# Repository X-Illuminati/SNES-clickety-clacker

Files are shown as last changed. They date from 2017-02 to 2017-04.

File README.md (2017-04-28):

```
     ______     ___   ___   _______     _______   _______
    / ___. \   /  /  /  /  /  ___  \   /  ____/  /  ___  \
   / /   / /  /  /  /  /  /  /  /  /  /  /      /  /  /  /
   | \  /_/  /  /  /  /  /  /  /  /  /  /___   /  /__/  /
  _ \ \     /  /  /  /  /  /__/  /  /  ____/  /      __/
 / / \ \   /  /  /  /  /  _____,'  /  /      /  ___.  \
/ /__/ /  /  /__/  /  /  /        /  /___   /  /   /  /
\_____/   \_______/  /__/        /______/  /__/   /__/

≡≡≡≡≡≡≡≡≡≡≡≡≡≡≡≡≡≡≡≡≡≡≡≡≡≡≡≡≡≡≡≡≡≡≡≡≡≡≡≡≡≡≡≡≡≡≡≡≡≡≡≡≡≡≡≡
#    C  L  I  C  K  E  T  Y  -  C  L  A  C  K  E  R    #
≡≡≡≡≡≡≡≡≡≡≡≡≡≡≡≡≡≡≡≡≡≡≡≡≡≡≡≡≡≡≡≡≡≡≡≡≡≡≡≡≡≡≡≡≡≡≡≡≡≡≡≡≡≡≡≡
    ______    ___     ____    ____     ______    _   __
 __/ ____/___/   |___/  _/_  / __ \   / ____/   / | / /
  / / __  __/ /| |___/ /____/ / / /__/ __/__   /  |/ /
 / /_/ /   / ___ | _/ /  __/ /_/ /__/ /_______/ /|  /__
 \____/   /_/  |_|/___/   /_____/  /_____/   /_/ |_/

                            /\
  /\-----------------------/__\---------------------/\
 /--\                    CONTENTS                  /--\
/`\/`\--------------------------------------------/`\/`\
¯¯¯¯¯¯                                            ¯¯¯¯¯¯
```
- [Introduction](#introduction)
- [Thaumaturgical Design](#thaumaturgical-design)
- [Reagents](#reagents)
- [Crafting Notes](#crafting-notes)
- [Epilogue](#epilogue)

## Introduction

Hail adventurer! I see my little trinket has caught your attention.
If you're interested, I'll tell you all about it. Just pull up a stool and order
your favorite libation. I can vouch for the quality of the ale but be warned:
the bartender is an incurable gossip!

What is it, you ask? Why, it's a SNES controller. Ha! It's barely recognizable
compared to your usual, mundane variety. But, I'll get to that...

Let me tell you why it's useful -- I used to have terrible problems with the
standard SNES controller. After years of adventuring I've developed what the
seven sages call sore-thumb-itosis. Even Morgia root can't treat it once the
disease reaches it's advances stage.  
Well, this sore-thumb-itosis was preventing me from making progress in my
adventures. I couldn't even make it to base camp most of the time.  
But, fortunately, I met a fellow adventurer one evening in an inn much like this
one. He told me that he used to be a great adventurer (until he took an arrow to
the knee), and told me of others he'd met who had a similar problem.
It turns out the issue is fundamental to the design of the stock controller --
the rubber membranes make only intermittent contact and lack any sort of tactile
feedback. This increases fatigue and leads to sore-thumb-itosis.

So I traveled to the far-away court of OSH Park where they produce bespoke
magical artifacts. There I consulted with their renowned thaumaturgists and
artificers and commissioned this bauble -- it employs tactile switch technology
to resolve the deficiencies of the standard controller.  
The artisans that crafted these tactile switches assure me that I could ascend
even to the heights of Mt. Ordeals and still have energy enough to take on an
ancient Balrog or the evil sorcerer Thanatos.  
(I'm not saying I believe any of that, but those gnomes sure have some pretty
good marketing.)

## Thaumaturgical Design

Well, I could go on about this all evening (and probably will if you let me!)
But I've already gotten ahead of myself. We should begin at the beginning --
with the design of the original SNES controller.
The design is fairly basic; a classic shift register. 60 times each second, the
state of the buttons are latched and shifted out, back to the SNES CPU.
The communication protocol is clearly based on a 4021 asynchronous shift
register; the latch signal is not lined up with a clock edge.

Nintendo has gone through a couple of revisions.
Originally, they had 2 8-bit shift registers daisy-chained together.
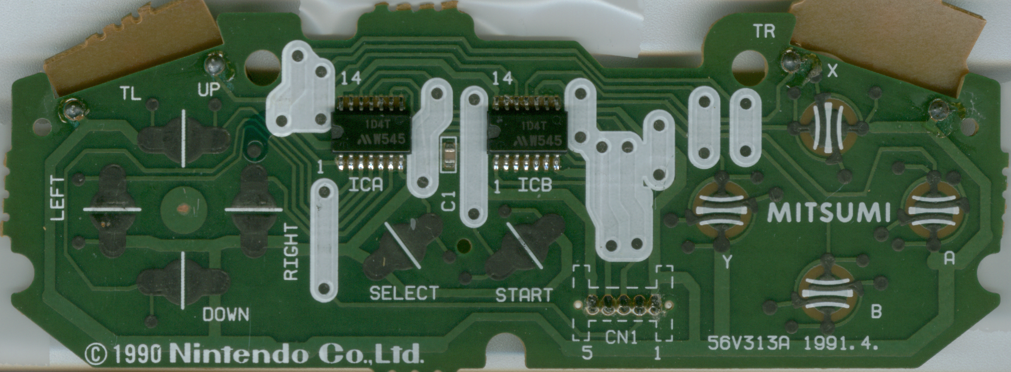
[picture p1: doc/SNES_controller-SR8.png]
Controller PCB with 8-bit shift registers

Latterly, they moved to a simpler layout with a single 16-bit shift register.
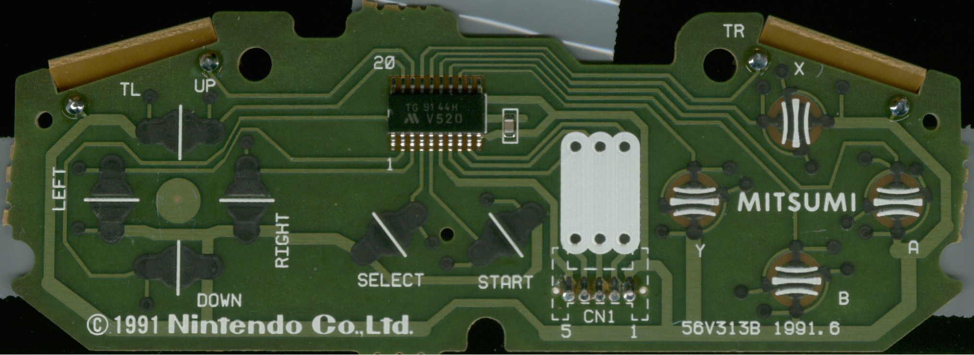
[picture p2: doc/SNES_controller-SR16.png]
Controller PCB with 16-bit shift register


The board is a single layer design, but makes use of a separate carbon-film
layer for the button pads and a few jumper tracks.  
There are some signs that they have created a custom shift register rather than
using a standard 4000-series component. The 8-bit shift registers have a
different pinout than the standard 4021. Also, tn both cases above, we can see
that they have omitted a number of important pull-up resistors, choosing to
instead integrate these into the IC, itself.

This was a little concerning, so I went to the trouble of mocking up a 4021
circuit on a breadboard.
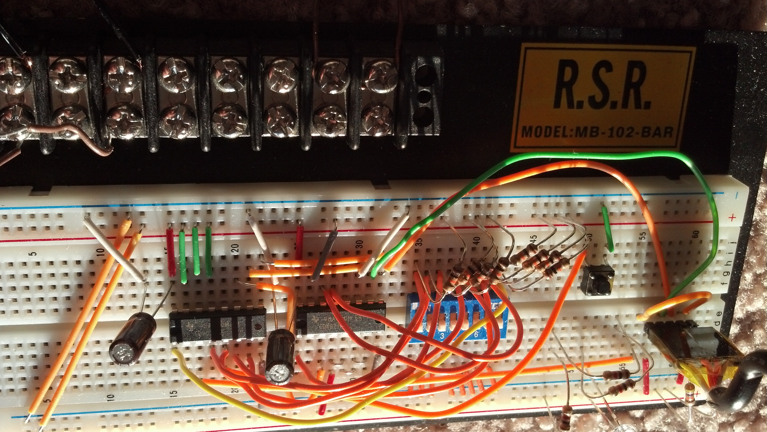
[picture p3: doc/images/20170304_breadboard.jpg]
Breadboard Mockup

It worked properly once the missing pull-ups were added.

My goal in this project was to reuse most of the existing controller.
This meant fitting into the mechanical envelope of the controller housing and
selecting switches that had the proper height to be actuated by the existing
plastic buttons. Another goal was to use all 3 copies of the board received from
OSH Park as a different piece of the overall layout.
[See below](#why-use-osh-park-for-pcb-manufacture) for more details.

The mechanical layout was perhaps the most difficult part with more than half of
the time spent simply rearranging components.

To create the board outline, I scanned in the controller and traced a one-to-one
DXF from the outline. Along with this outline, I also included drill hole
locations and divided the overall board into thirds. I then mirrored this and
created the PCB routing outline from the intersection of the mirrored and
unmirrored copies.
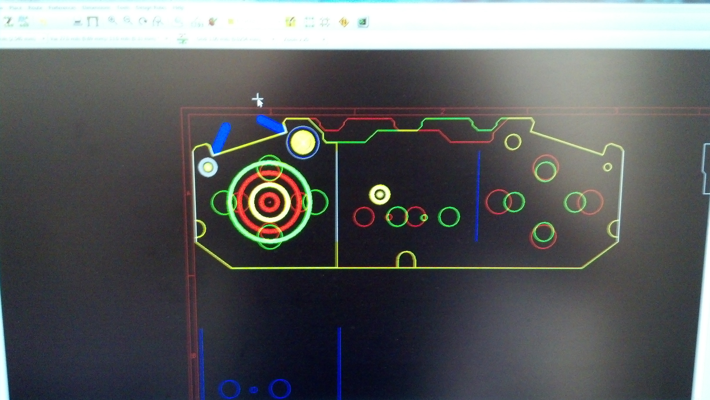
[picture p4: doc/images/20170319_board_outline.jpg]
Board Outline


The plastic shell of the controller has several features molded into it that
provide support for the PCB. I wanted to make sure that I didn't put any
components in a position where they would foul against these, so I added several
annotations to some nonfunctional layers in order to mark the keep-out regions.
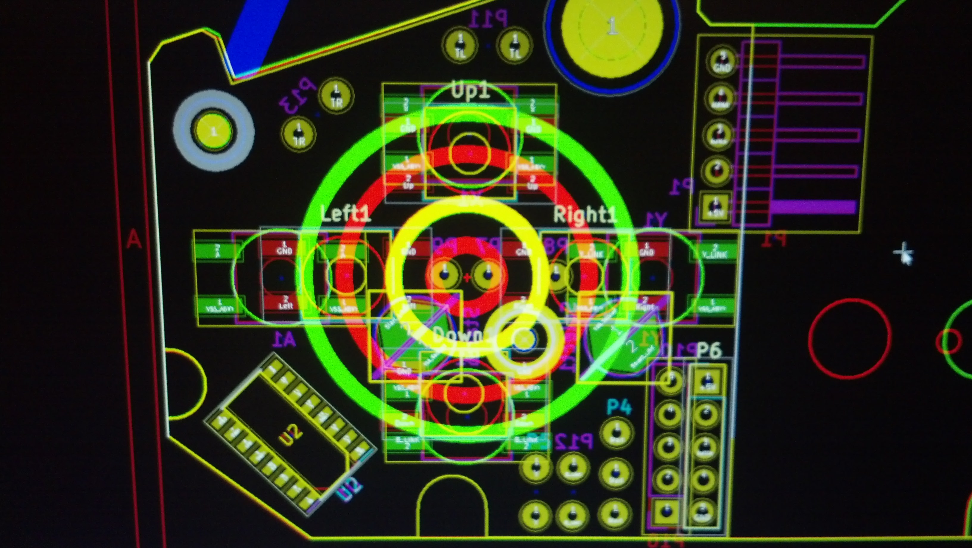
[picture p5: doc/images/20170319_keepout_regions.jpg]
Keep-out Regions


---
I see you still have questions.  
#### Why not attach switches to the existing controller PCB?
Alas, this would be somewhat impractical. The existing switch contacts are
covered with a carbon film that is difficult to scrape off and many of the
traces are quite thin so that soldering to them would not provide adequately
mechanical anchoring.
However, this was the route chosen for the left and right trigger switches.

#### Why not create new PCBs for the trigger switches?
This PCB is modeled, but OSH Park doesn't support V-scoring so it would have to
be submitted as a separate design.

#### Why use OSH Park for PCB manufacture?
OSH Park is reasonably cheap and fast. Also, their pricing includes 3 copies of
the design and 2 layers, top and bottom. A shrewd buyer can use this to their
advantage!
By mirroring the board layout both sides can be used, one as the left half and
one as the right half, with the 3rd copy as a spare.
Furthermore, the design could be split into thirds with some pads and traces
serving double duty. The layout is a little more effort, but the manufacturing
cost is reduced by about 50%.

#### How do you test such a complicated design?
It mostly depends on getting things right in the schematic, then the layout
tool will do most of the work for you. When using pads and tracks for multiple
purposes they have to be shown that way in the schematic. Sometimes this
involves extra care to separate power and ground. In other cases it just means
creating a more descriptive label for the net to avoid confusion.
Still, it is easy to get messed up when going through board-to-board jumper
connections or when using two legs of a switch to jump over some other tracks.
To check for this, I made a simple cardboard mockup and highlighted the traces
as I reviewed the path for each signal in the layout.
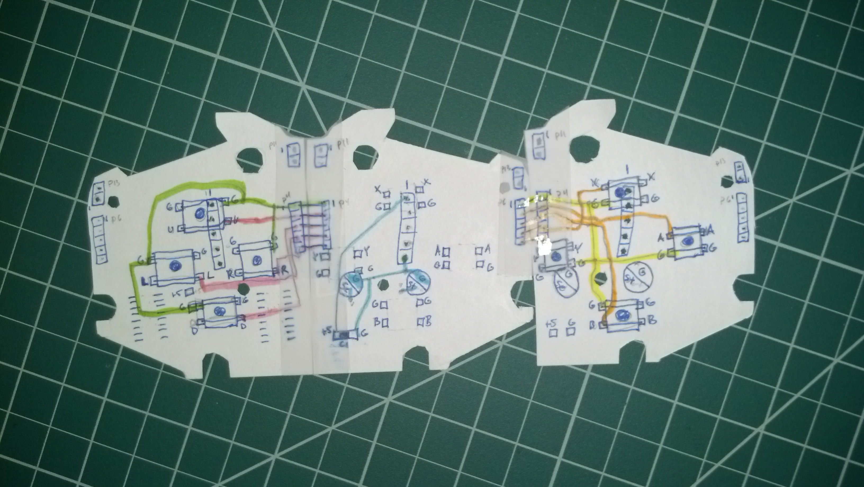
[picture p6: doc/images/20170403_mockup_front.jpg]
Cardboard Mockup Front

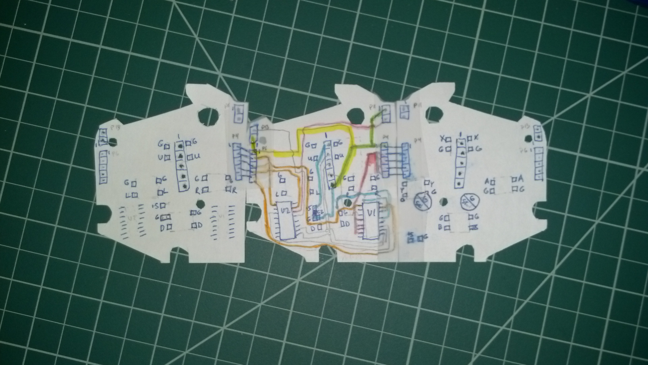
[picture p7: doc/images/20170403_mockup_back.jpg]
Cardboard Mockup Back


#### What about those capacitors?
The value was not chosen very scientifically. A review of typical application
circuits indicated a value of 0.1 or 0.01 µF. This is a fairly low speed
application, so the value is probably not critical and I just chose 0.1 µF
arbitrarily.
Those who are concerned with it might follow the methodology in
[this Youtube video](https://www.youtube.com/watch?v=9EaTdc2mr34)
from Alan Wolke (w2aew).

## Reagents

So, you're thinking you might build one for yourself, aye?
It can be done by any experienced thaumaturgist and the fine folks of OSH Park
will be happy to oblige by replicating the design.

So what about the remaining reagents?
None of them are particularly uncommon, so you won't need to fight your way to
the top of Darm Tower to get what you need. Just seek out the nearest outfitter,
guild shop, or magical supply.
I recommend The Sharper Mage in Lycaeum or, failing that, DigiKey.

Here's a list of what you'll need:

### Core Components
* [2x] 4021 8-bit asynchronous shift register in SOIC-16 package
* [2x] ceramic capacitor in 1206 SMD package
  * Exact value is not particularly important
  * Recommend 0.01 µF - 10 µF
* [14x] pull-up resistors in 1206 SMD package
  * Exact value is not particularly important
  * Recommend 10 kΩ - 100 kΩ
* [4x] D-Pad switches (3.8 mm actuator height, Gullwing SMD package)
  * Tactile pushbutton, SPST-NO
  * Recommend comparing exact dimensions to the [KSC datasheet](doc/README.md)
* [4x] ABXY switches (4.3 mm actuator height, Gullwing SMD package)
  * Tactile pushbutton, SPST-NO
  * Recommend comparing exact dimensions to the [KSC datasheet](doc/README.md)
* [10x] Wire Links for Board-to-Board Wiring
  * 0.1 in. (2.54mm) spacing

### Optional Components
* [2x] L/R Trigger switches (7.7 mm actuator height, Gullwing SMD package)
  * Optional, not included in OSH Park-optimized design
  * Tactile pushbutton, SPST-NO
  * Recommend comparing exact dimensions to the [KSC datasheet](doc/README.md)
* [2x] 2-pin headers for trigger boards, 0.1 in. (2.54 mm) spacing
* [2x] 2-pin housing for trigger board wires, 0.1 in. (2.54 mm) spacing
* [1x] 5-pin header for CN1, 0.1 in. (2.54 mm) spacing
* [1x] 5-pin housing for CN1 cable, 0.1 in. (2.54 mm) spacing
* [9x] 0.1 in. (2.54 mm) wire crimps

If you're looking for specific recommendations or need help with DigiKey's
telepathic ordering system, try these mantras:

### Links for Core Components
* [2x] [ON Semi mc14021b](https://www.digikey.com/short/3wn7b8)
* [2x] [0.1 µF 1206 SMD ceramic capacitor](https://www.digikey.com/short/3wn7bm)
* [14x] [47 kΩ 1206 SMD resistor](https://www.digikey.com/short/3wn75j)
* [4x] D-Pad switch
  * No good recommendation yet
  * Pads are set up for [C&K KSC201GLFS](https://www.digikey.com/short/3wn7bn).
    However, this switch does not have a tall enough actuator and has too tall
    of a switch body.
  * The [Bourns 7914H](https://www.digikey.com/short/3nt825) works acceptably
    but doesn't fit the pads and doesn't have a great feel, either.
  * [This search](https://www.digikey.com/short/3nt8n5) may be helpful.
* [4x] [C&K KSC701GLFS](https://www.digikey.com/short/3wn7b0)

### Links for Optional Components
* [2x] [C&K KSC621GLFS](https://www.digikey.com/short/3wn7b1)
* [2x] [2-pin header](https://www.digikey.com/short/3wn728)
* [2x] [2-pin housing](https://www.digikey.com/short/3wn7d8)
* [1x] [5-pin header](https://www.digikey.com/short/3wn7d2)
* [1x] [5-pin housing](https://www.digikey.com/short/3wn7d0)
* [9x] [0.1 in. wire crimps](https://www.digikey.com/short/3wn7vh)

## Crafting Notes

Once you've acquired your reagents and the blank PCB from OSH Park, you can
begin the assembly process.  
Start by inspecting the PCBs.
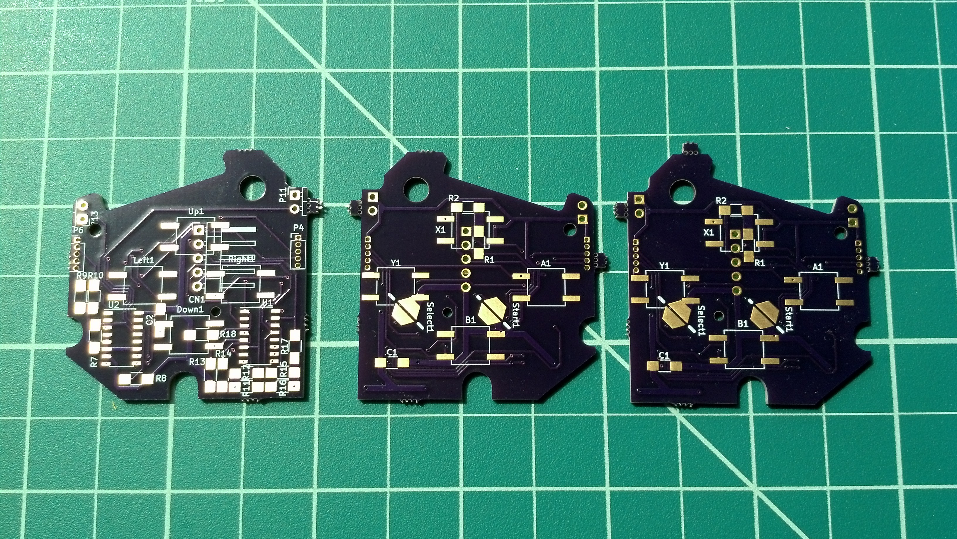
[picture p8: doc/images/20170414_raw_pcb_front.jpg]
Unstuffed PCB

You'll want to make note of any defects. In this design each board has an
unused side (or mostly unused), so you can use just the good side of each board
if there are defects.

Some cleanup of the board edge will be necessary. The mousebites from the
panelization will need to be trimmed off and a lite sanding of the edges could
be helpful.  
You can also test the mechanical fit by placing the boards in the controller
housing.
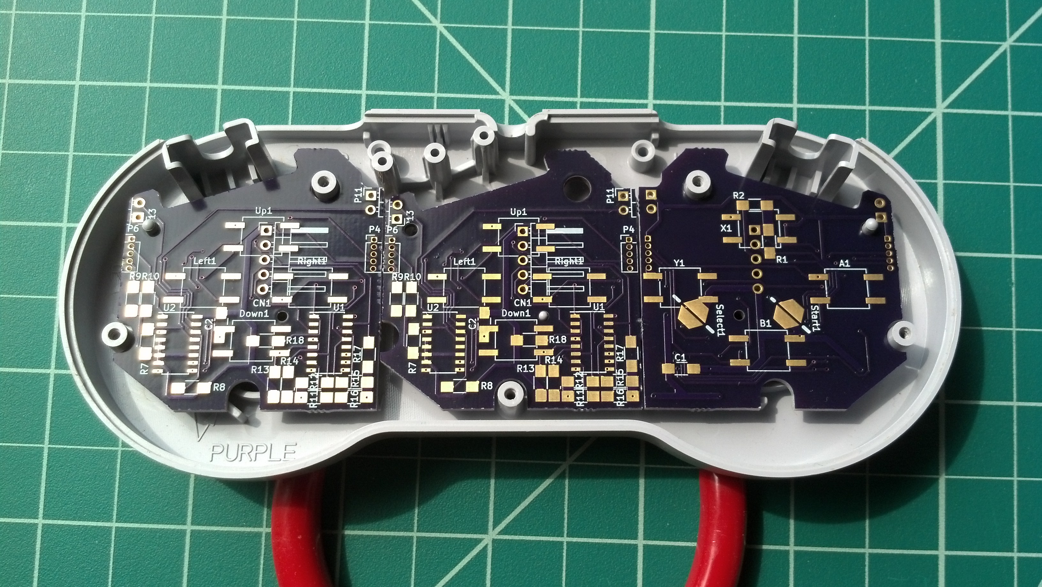
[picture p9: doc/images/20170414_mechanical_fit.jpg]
Test Fit


It is a good strategy to prep your workspace; you will want to avoid any
interruptions in your incantations.  
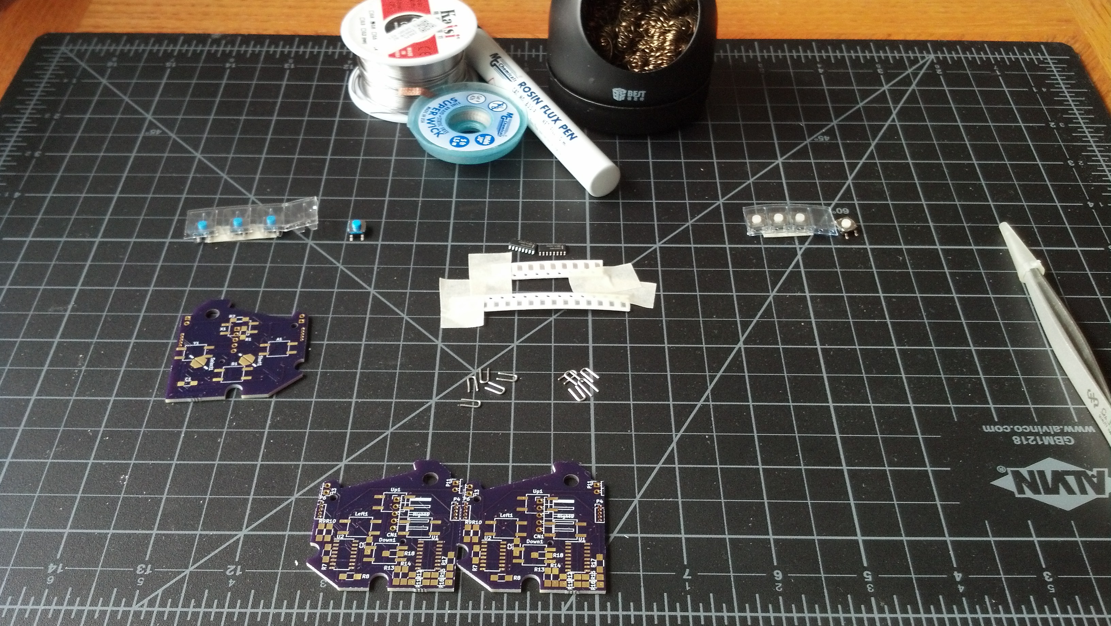
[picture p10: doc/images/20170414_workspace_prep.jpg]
Workspace Prep

(Note: soldering iron off-screen.)

The small parts involved can be tricky to work with; I recommend taping the
strips of parts to your work surface to avoid getting scattered by any chance
breeze. And definitely clear the area of any small children or animals.
(Luckily, DigiKey anticipates this need and includes a free cat toy with every
order!)

Here, I've placed all of the front side parts:
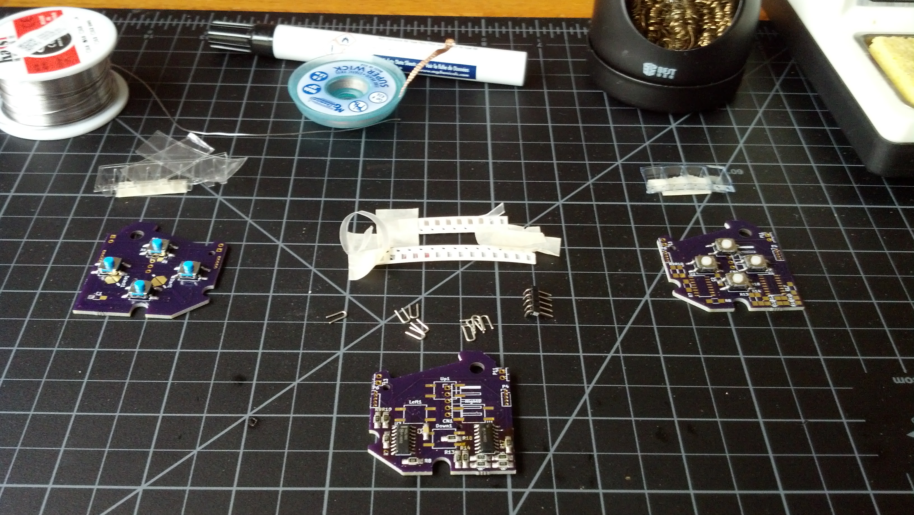
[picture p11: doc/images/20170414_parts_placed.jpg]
Parts Placed


And a closeup:
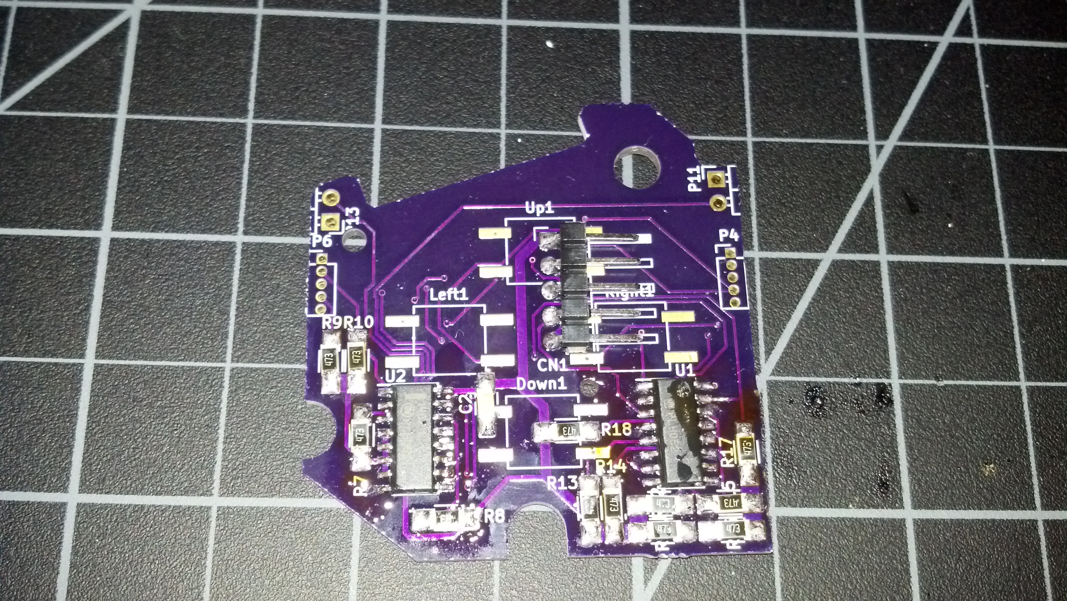
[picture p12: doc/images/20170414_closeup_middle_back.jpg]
Closeup Middle Back

(Note: the right-angle header on CN1 needs to face the other direction.)

The middle section is a little bit special in that it has parts on the back as
well.
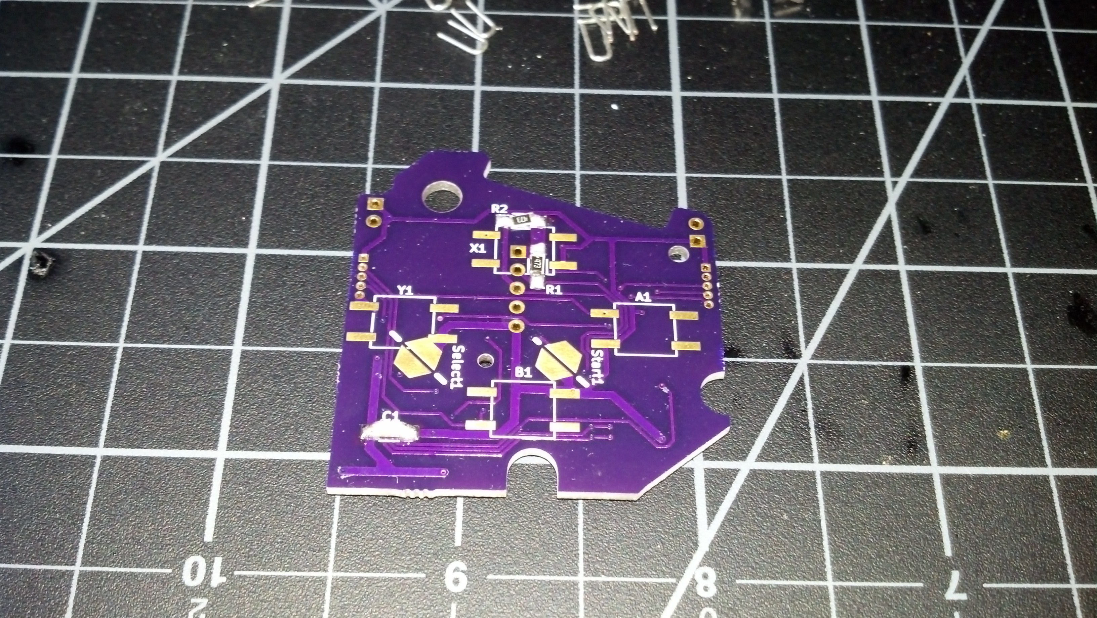
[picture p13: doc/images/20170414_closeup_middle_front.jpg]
Closeup Middle Front


The next step is to link the boards together. I found it easiest to assemble
them in the controller housing and tack down the jumper links.
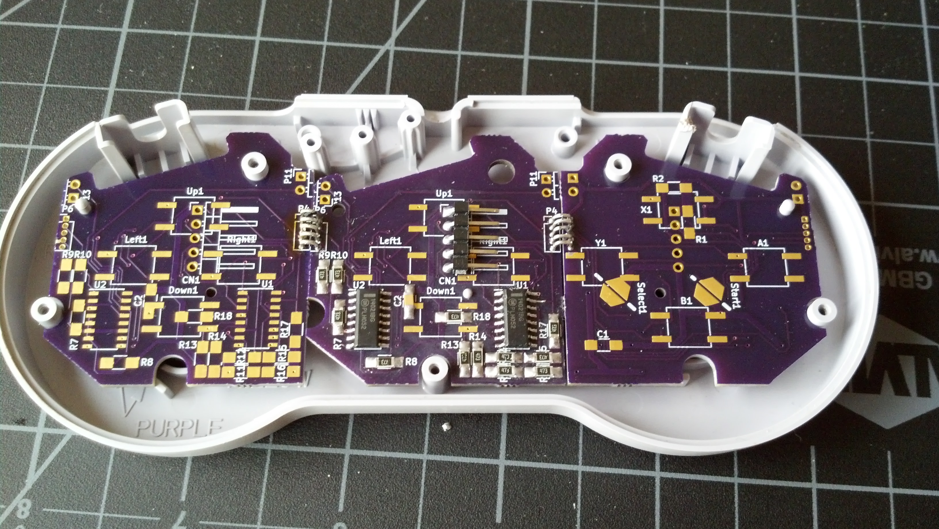
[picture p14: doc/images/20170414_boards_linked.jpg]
Boards Linked

(Note: the right-angle header on CN1 needs to face the other direction.)

The jumper links are very small and can be difficult to solder without bridging.
If you have problems, remember to apply lots of flux and use a fine tip on your
soldering iron so you can heat up the pad and just a single link.  
Use a multimeter continuity test to ensure none of the links are shorted.
It can also be good to test end to end continuity between ground and the input
pin on the IC (when the appropriate button is pressed).

Once this is finished, there remains a few details to take care of.  
An optional step is to put tactile switches on the trigger boards.
This can be done by scraping off the solder mask over the two traces and tacking
either side of the switch to them.
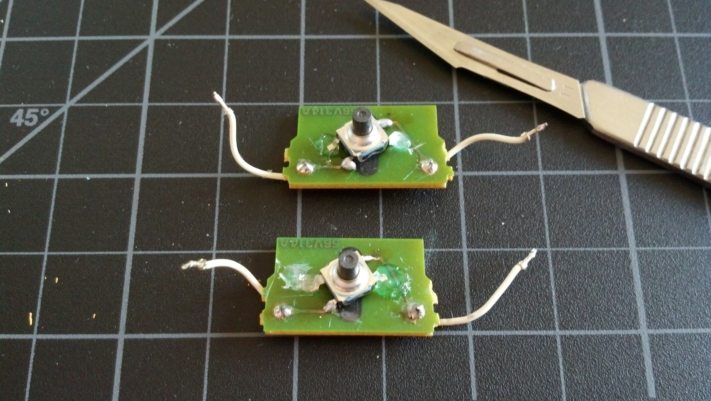
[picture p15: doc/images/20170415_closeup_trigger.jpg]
Trigger Board Closeup

Some form of glue is probably necessary, but hot-melt glue doesn't really work
very well. Probably, a two-part epoxy is recommended.

Connect the trigger boards to P11 and P13. I had to add longer wires for this.
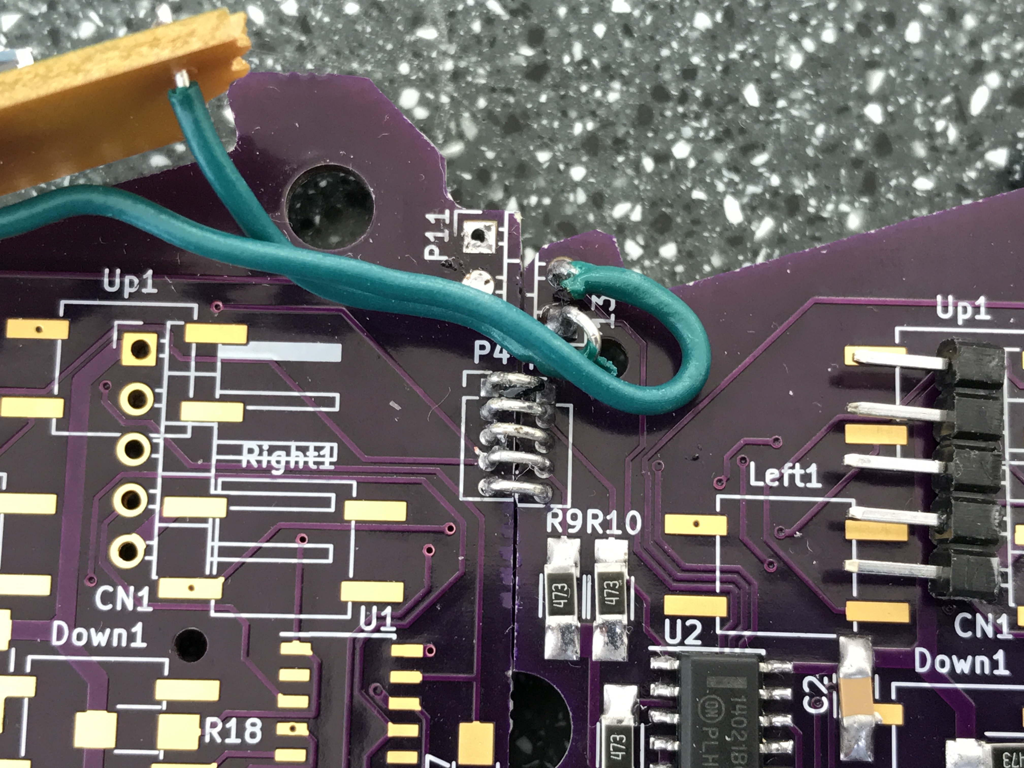
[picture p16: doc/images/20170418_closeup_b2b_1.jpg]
Closeup of Board-to-Board Connections

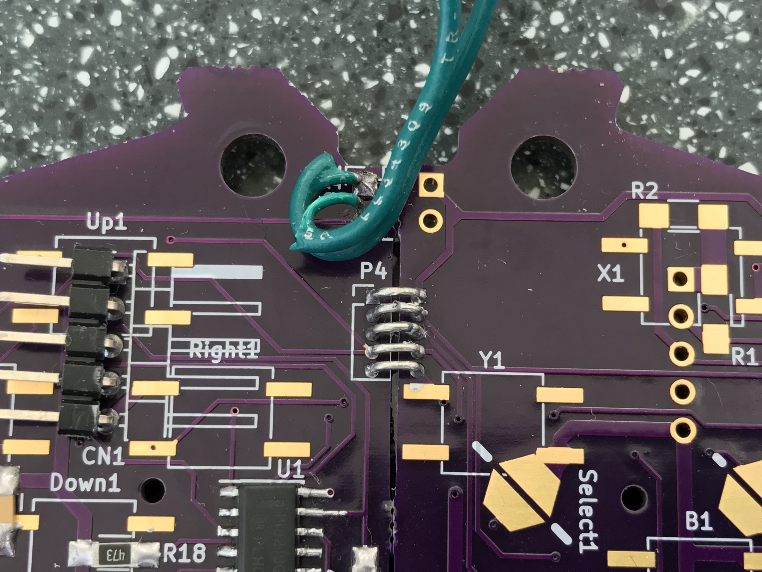
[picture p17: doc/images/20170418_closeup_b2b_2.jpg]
Closeup of Board-to-Board Connections


Another issue comes up with the choice of switches for the D-Pad and a couple
of issues with the plastic D-Pad button disc.  
The D-Pad needs a fair amount of clearance around above the switch body or it
will foul against it and fail to actuate the switch. The switch needs to be
between 3.7 mm and 4 mm. 3.8 mm is probably ideal, but might not work if the
switch body is really tall.  
You might be able to carve out some extra clearance in your D-Pad disc:
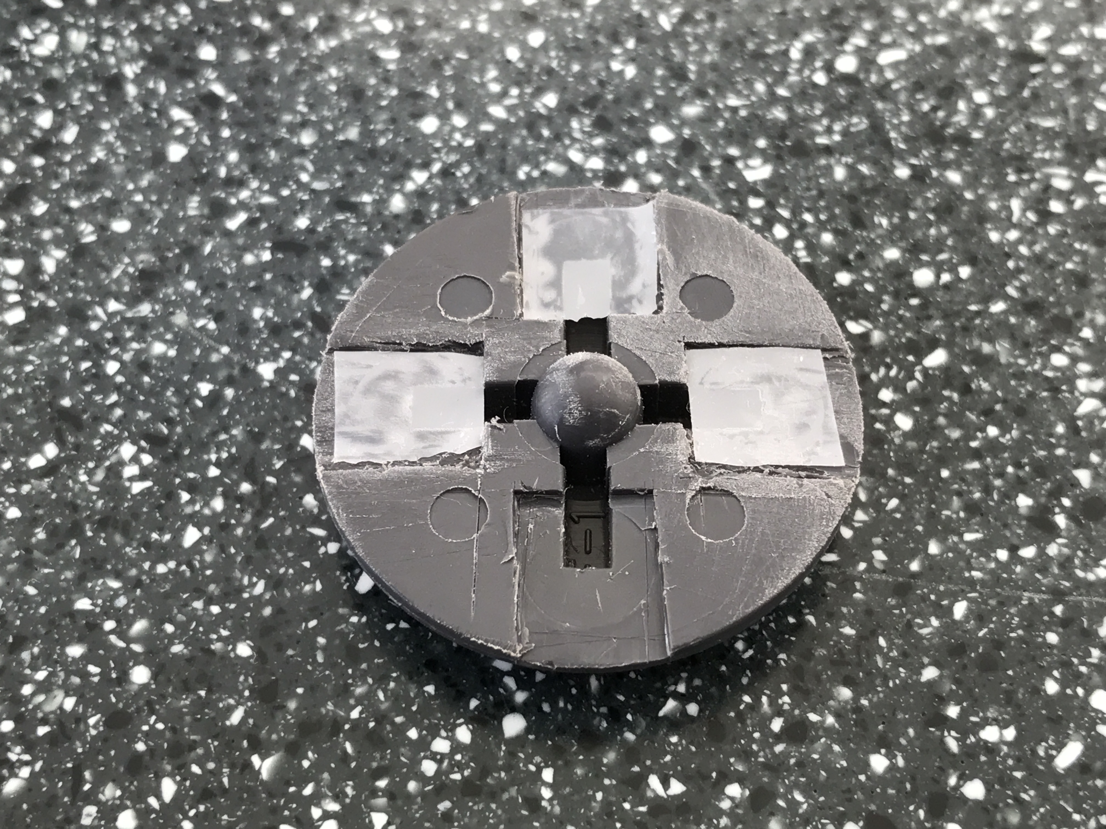
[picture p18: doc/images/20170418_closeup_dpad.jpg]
Closeup of D-Pad Modification

Note that it is very difficult to do this with a utility knife and impossible
without cutting yourself.  
In the image above, I just covered the slots with tape, which sort of works.
It would be better to fill the slots with epoxy so that the actuator of the
tactile switch doesn't slip up into it.

Here is the fully assembled controller:
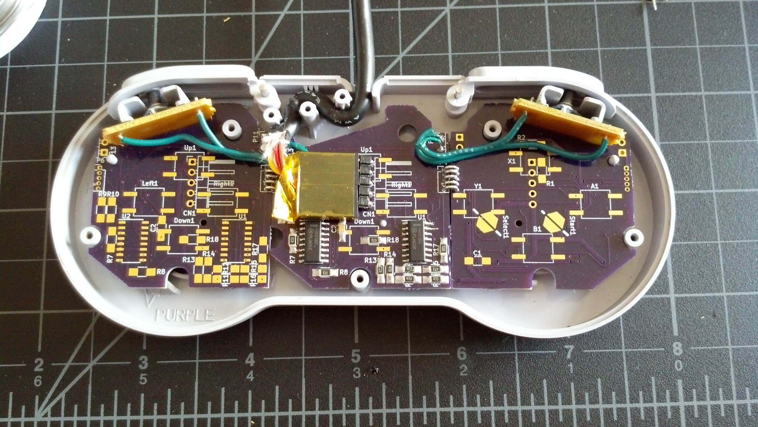
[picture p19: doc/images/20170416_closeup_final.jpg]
Final Assembly


And an action shot!
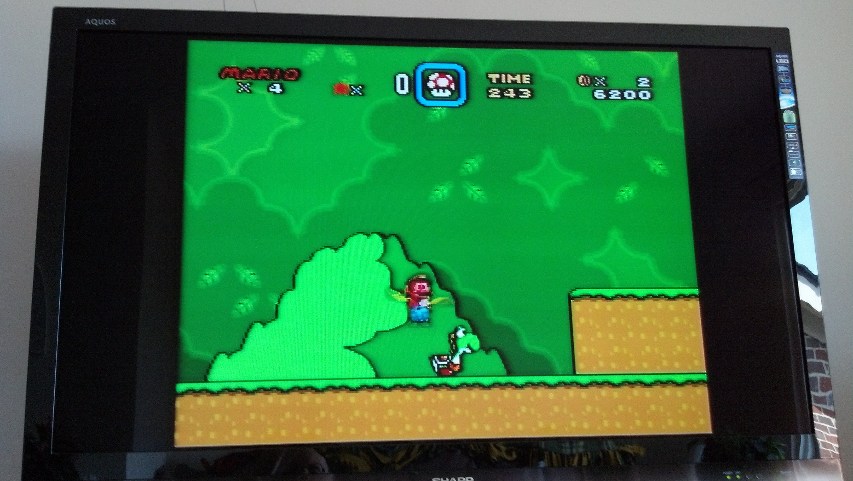
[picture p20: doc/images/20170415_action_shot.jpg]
Action Shot


## Epilogue

Well, my mug's nearly empty now, and Trammel is high in the sky.
Perhaps tomorrow will bring renewed invigoration and I'll make some improvements
to the design or add some tips for future adventurers.  
There's plenty of work left to do.
1. Improvements to the layout
   * combine P11 and P13 (TR/TL)
   * route TR/TL through the board-to-board connectors (P4 and P6)
   * general routing improvements
     * route ground path around the outside of the board
     * route +5 V down center
     * route the bottom side traces predominantly vertical
     * route the top side traces predominantly horizontal
     * rotate U1 180°
     * rotate U2 180° or, possibly, 90° CCW
     * move P4/P6 back from board edge to sneak a trace in between
   * change pads on passives to non "hand-soldering" versions
     (these are excessively large)
2. Create DIP package variant
(or perhaps support both DIP and SMT in one design).
3. Create 3D-printable models for select/start button caps

Copywrite © 2017 Chris Baker.
[CC-BY-4.0](https://creativecommons.org/licenses/by/4.0/)
See [LICENSE.txt](LICENSE.txt) for details.

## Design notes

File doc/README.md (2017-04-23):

# Documentation Summary
- `Sci.Electronics-FAQ-SNES Protocols.html`
  Documentation/reverse-engineering of the controller protocol and pinout
- `20170204-SNES Controller Mech.jpg`
  Original Controller PCB trace (hand-drawn)
- `20170204-SNES Controller Schematic.jpg`
  Original Controller Schematic (hand-drawn)
- `SNES_controller-SR8.png`
  Scan of original controller PCB version A with two 8-bit shift registers
- `SNES_controller-SR16.png`
  Scan of original controller PCB version B with one 16-bit shift register
- `SNES_controller_LR.png`
  Scan of original controller trigger button PCB
- `cd4021b.pdf`
  Datasheet for TI CD4021B (CDIP-16)
- `mc14021bdg.pdf`
  Datasheet for ON Semi MC14021B (SOIC-16)
- `ckswitches-ksc-series.pdf`
  Datasheet for C&K Components KSC-series Tact Switches
- `ckswitches-KSC201GLFS.stp`
  3D model file for KSC-201-GLFS tact switch (downloaded from C&K [website](http://www.ckswitches.com/products/switches/product-details/Tactile/KSC2/))
- `ckswitches-KSC621GLFS.stp`
  3D model file for KSC-621-GLFS tact switch (downloaded from C&K [website](http://www.ckswitches.com/products/switches/product-details/Tactile/KSC6/))
- `ckswitches-KSC701GLFS.stp`
  3D model file for KSC-701-GLFS tact switch (downloaded from C&K [website](http://www.ckswitches.com/products/switches/product-details/Tactile/KSC7/))

# Non-distributable Documentation
Some of the documentation is non-distributable (usually due to copywrite).
The softlinks in this directory will be broken until you retreive these files
from an authorized distributor and place them in the `DO_NOT_DISTRIBUTE`
directory.
Here are some potentially useful hyperlinks:
- [`Sci.Electronics-FAQ-SNES Protocols.html`](http://repairfaq.org/REPAIR/F_SNES.html)
  Copywrite © Jim Christy
- [`cd4021b.pdf`](http://www.ti.com/lit/ds/symlink/cd4021b.pdf)
  Copywrite © 2003 Texas Instruments Incorporated
- [`mc14021bdg.pdf`](http://www.onsemi.com/pub/Collateral/MC14014B-D.PDF)
  Copywrite © Semiconductor Components Industries, LLC, 2014
- [`ckswitches-ksc-series.pdf`](http://www.ckswitches.com/media/1459/ksc.pdf)
  Copywrite © C&K Components, Inc
- [`ckswitches-KSC201GLFS.stp`](http://comnet.louisverne.net:8050/webServiceWakefly/rest/GetProductDrawingByProductNumber/KSC201GLFS/STP)
  Copywrite © C&K Components, Inc
- [`ckswitches-KSC621GLFS.stp`](http://comnet.louisverne.net:8050/webServiceWakefly/rest/GetProductDrawingByProductNumber/KSC621GLFS/STP)
  Copywrite © C&K Components, Inc
- [`ckswitches-KSC701GLFS.stp`](http://comnet.louisverne.net:8050/webServiceWakefly/rest/GetProductDrawingByProductNumber/KSC701GLFS/STP)
  Copywrite © C&K Components, Inc

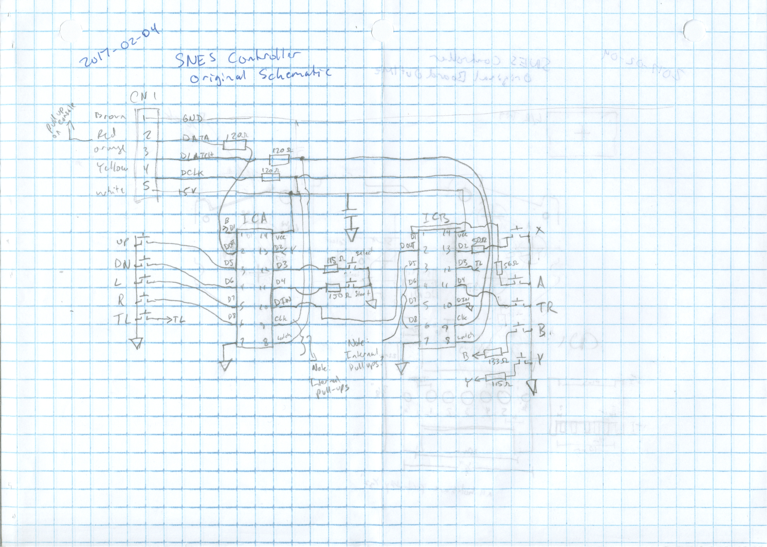
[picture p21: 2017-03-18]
doc/20170204-SNES Controller Schematic.jpg

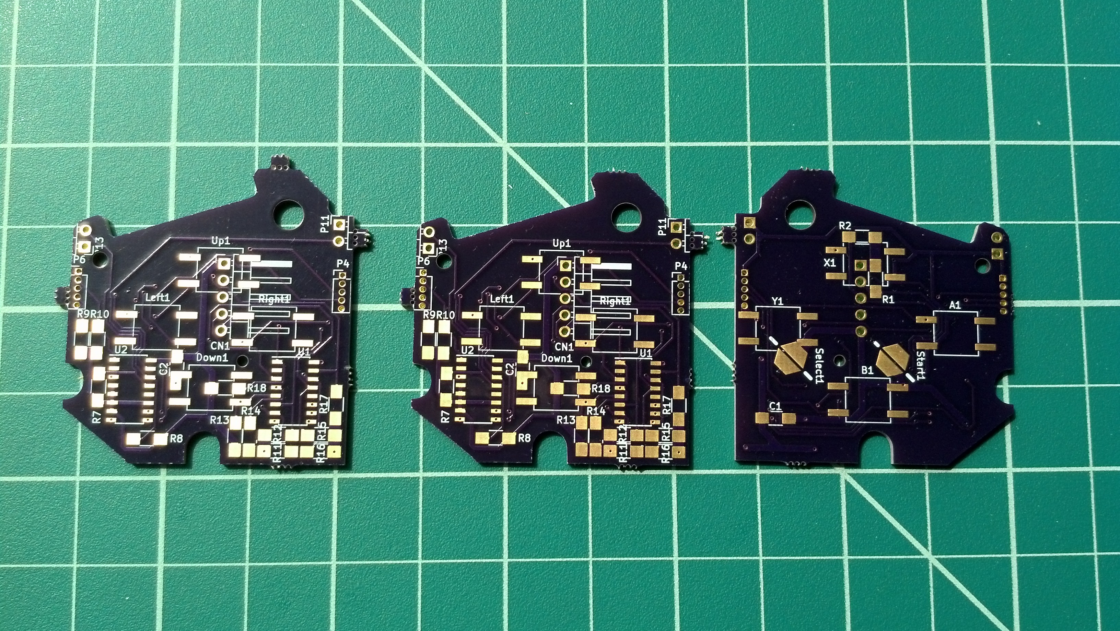
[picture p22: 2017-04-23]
doc/images/20170414_raw_pcb_back.jpg

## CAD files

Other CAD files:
doc/ckswitches-KSC701GLFS.stp
freecad/LR-sketch.FCStd
doc/ckswitches-KSC201GLFS.stp
freecad/Controller-sketch.FCStd
doc/ckswitches-KSC621GLFS.stp
freecad/Controller-sketch.dxf
freecad/LR-sketch.dxf

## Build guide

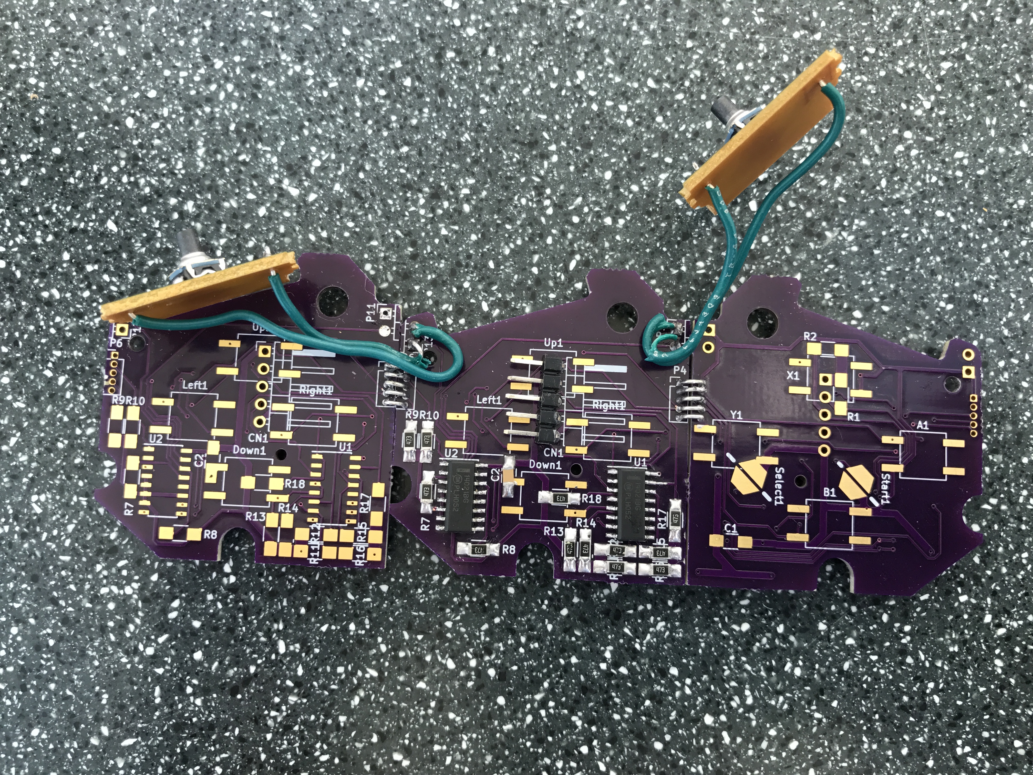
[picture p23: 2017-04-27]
doc/images/20170418_assembly_back.jpg

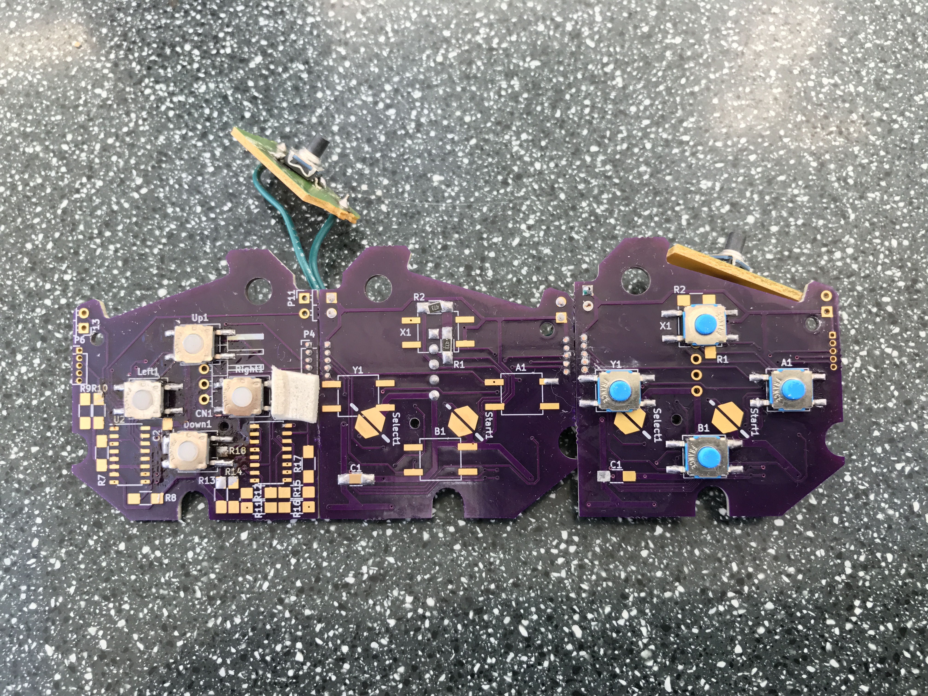
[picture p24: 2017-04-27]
doc/images/20170418_assembly_front.jpg

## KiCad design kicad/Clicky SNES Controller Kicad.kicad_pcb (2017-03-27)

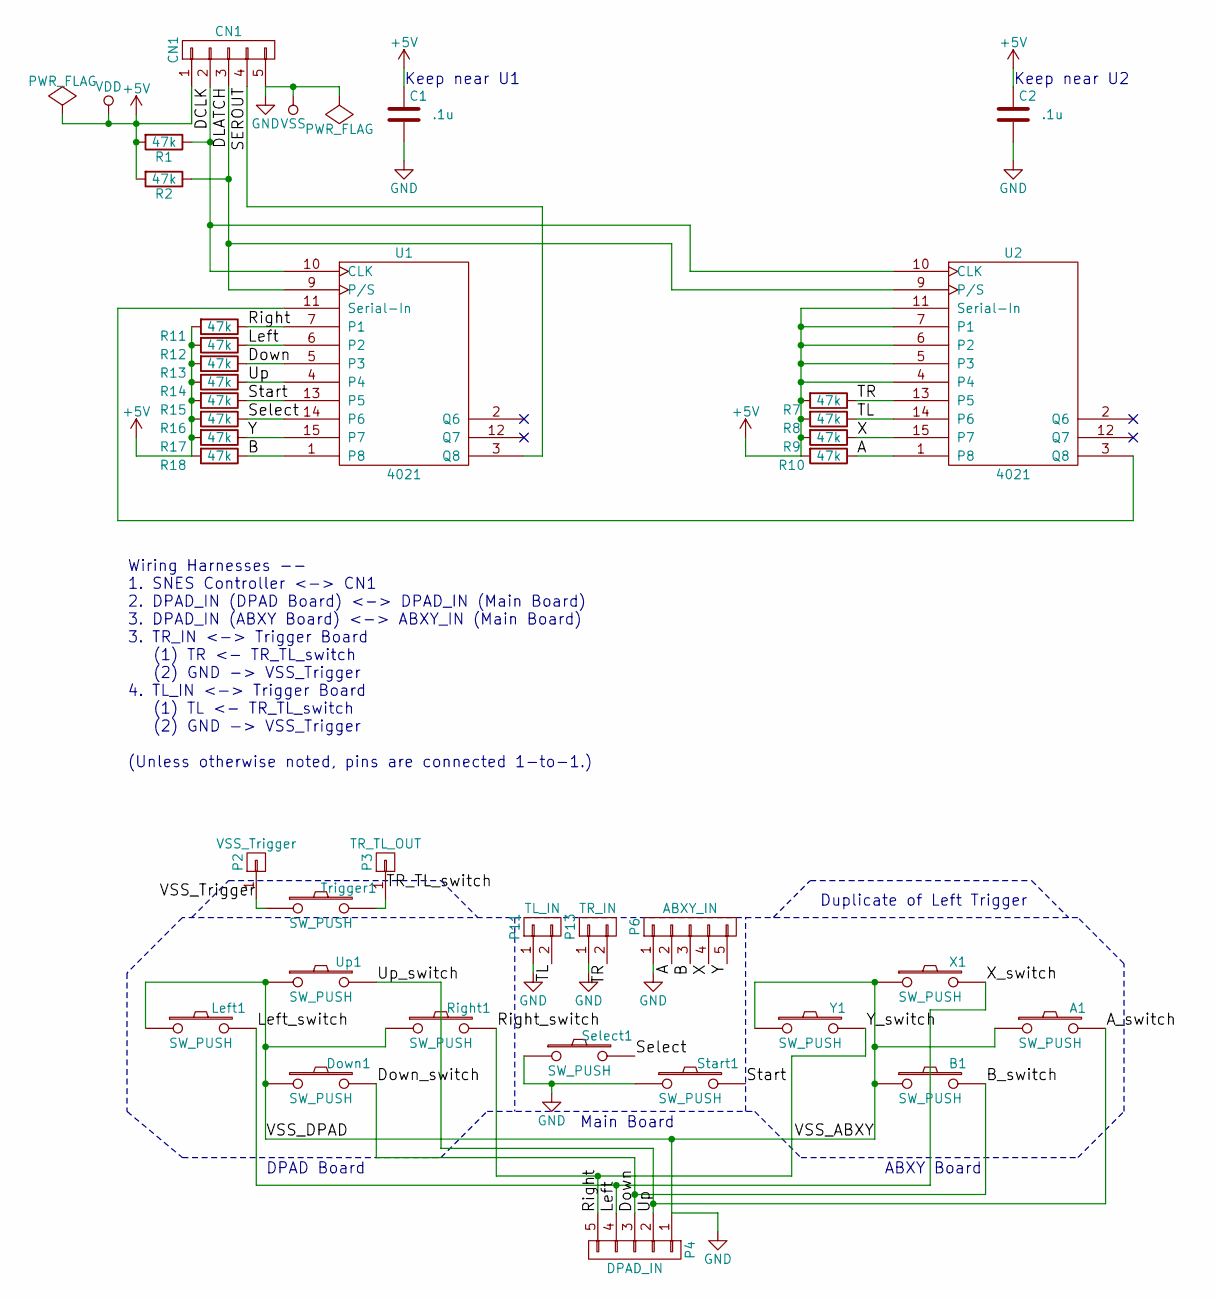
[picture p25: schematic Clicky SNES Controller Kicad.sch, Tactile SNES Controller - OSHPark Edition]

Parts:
A1: SW_PUSH; SW_SPST_KSC7-G
B1: SW_PUSH; SW_SPST_KSC7-G
C1, C2: .1u; C_1206_HandSoldering
CN1: CN1; Pin_Header_Angled_1x05_Pitch2.54mm
Down1: SW_PUSH; SW_SPST_KSC2-G
Left1: SW_PUSH; SW_SPST_KSC2-G
P2: VSS_Trigger; Pin_Header_Straight_1x01_Pitch2.54mm
P3: TR_TL_OUT; Pin_Header_Straight_1x01_Pitch2.54mm
P4: DPAD_IN; Pin_Header_Straight_1x05_Pitch1.27mm
P6: ABXY_IN; Pin_Header_Straight_1x05_Pitch1.27mm
P11: TL_IN; Pin_Header_Angled_1x02_Pitch2.54mm
P13: TR_IN; Pin_Header_Angled_1x02_Pitch2.54mm
R1, R2, R7, R8, R9, R10, R11, R12, R13, R14, R15, R16, R17, R18: 47k; R_1206_HandSoldering
Right1: SW_PUSH; SW_SPST_KSC2-G
Select1: SW_PUSH; SW_SPST_Plated_Pad_5.5mm
Start1: SW_PUSH; SW_SPST_Plated_Pad_5.5mm
Trigger1: SW_PUSH; SW_SPST_KSC6-G
U1, U2: 4021; SOIC-16_3.9x9.9mm_Pitch1.27mm
Up1: SW_PUSH; SW_SPST_KSC2-G
X1: SW_PUSH; SW_SPST_KSC7-G
Y1: SW_PUSH; SW_SPST_KSC7-G

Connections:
+5V: C1.1, C2.1, CN1.1, R1.2, R2.2, R7.2, R8.2, R9.2, R10.2, R11.2, R12.2, R13.2, R14.2, R15.2, R16.2, R17.2, R18.2, U1.16 (VDD), U2.4, U2.5 (P3), U2.6 (P2), U2.7 (P1), U2.11 (Serial-In), U2.16 (VDD)
/A: P6.2, R10.1, U2.1 (P8)
/A_switch: A1.2, P4.2, R14.1, U1.4, Up1.2
/B: P6.3, R18.1, U1.1 (P8)
/B_switch: B1.2, Down1.2, P4.3, R13.1, U1.5 (P3)
/DCLK: CN1.2, R1.1, U1.10 (CLK), U2.10 (CLK)
/DLATCH: CN1.3, R2.1, U1.9 (P/S), U2.9 (P/S)
/Left: Left1.2, P4.4, R12.1, U1.6 (P2), X1.2
/Right: P4.5, R11.1, Right1.2, U1.7 (P1), Y1.2
/SEROUT: CN1.4, U1.3 (Q8)
/Select: R16.1, Select1.2, U1.14 (P6)
/Start: R15.1, Start1.2, U1.13 (P5)
/TL: P11.2, R8.1, U2.14 (P6)
/TR: P13.2, R7.1, U2.13 (P5)
/VSS_Trigger: P2.1, Trigger1.1
/X: P6.4, R9.1, U2.15 (P7)
/Y: P6.5, R17.1, U1.15 (P7)
GND: A1.1, B1.1, C1.2, C2.2, CN1.5, Down1.1, Left1.1, P4.1, P6.1, P11.1, P13.1, Right1.1, Select1.1, Start1.1, U1.8 (VSS), U2.8 (VSS), Up1.1, X1.1, Y1.1
unnamed: P3.1, Trigger1.2
unnamed: U1.11 (Serial-In), U2.3 (Q8)

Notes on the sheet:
Duplicate of Left Trigger
Wiring Harnesses -- 1. SNES Controller <-> CN1 2. DPAD_IN (DPAD Board) <-> DPAD_IN (Main Board) 3. DPAD_IN (ABXY Board) <-> ABXY_IN (Main Board) 3. TR_IN <-> Trigger Board (1) TR <- TR_TL_switch (2) GND -> VSS_Trigger 4. TL_IN <-> Trigger Board (1) TL <- TR_TL_switch (2) GND -> VSS_Trigger (Unless 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
Keep near U1
Keep near U2
Main Board
DPAD Board
ABXY Board

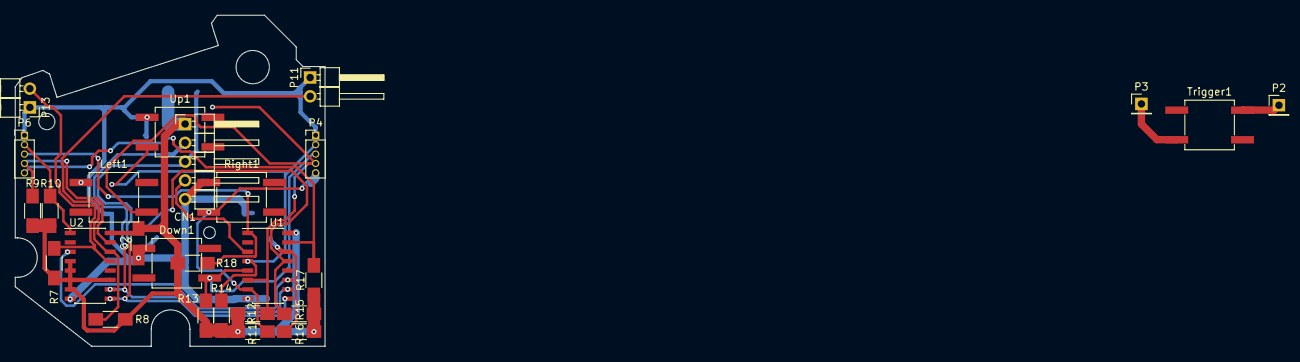
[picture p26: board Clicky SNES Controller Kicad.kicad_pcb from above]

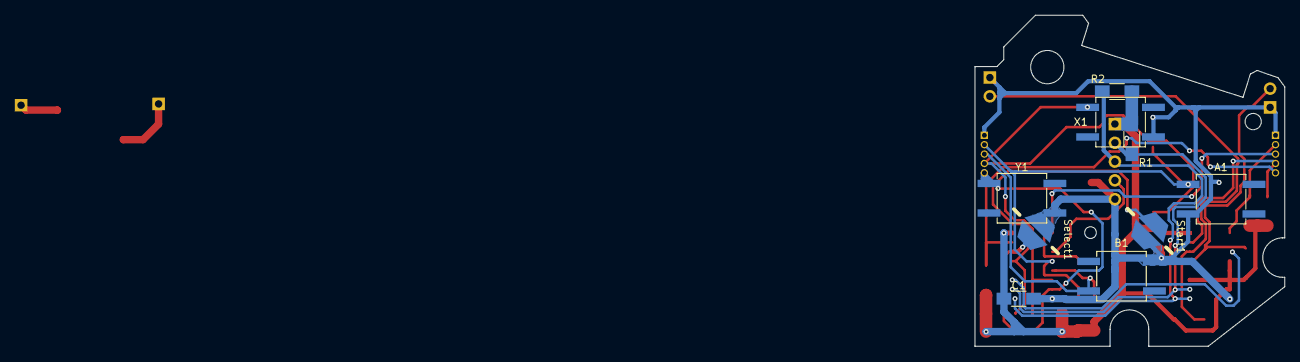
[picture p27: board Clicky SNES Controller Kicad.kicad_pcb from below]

Board: 2 copper layers, 41.9 x 44.8 mm, 36 parts (9 on the bottom side), 20 nets.

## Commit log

2017-02-21 Initial schematic and documentation
    [Clicky SNES Controller Kicad.kicad_pcb, Clicky SNES Controller Kicad.sch]
2017-02-21 Schematic Rev 2 - Reduce connector count
    -refactor the design to reduce the amount of board-to-board wires
    -label board-to-board connectors
    -add board-to-board wiring documentation
    -split voltage domains between the two shift registers (creating 2 new
    parts in the project cache lib)
    -move custom cmos4000 lib out of the project directory
    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
    [Clicky SNES Controller Kicad.sch]
2017-02-26 PCB Rev 1: Create basic board outline
    Scanned in the original circuit board and imported the vector drawing.
    Roughed-out the board outline so that buttons will be in relatively
    the correct place and board will fit within the existing plastic
    envelope of the controller.
    [Clicky SNES Controller Kicad.kicad_pcb]
2017-02-26 Add PCB backup file to gitignore
2017-02-26 Add scans of original controller PCB
2017-02-26 Add vectorized DXF versions of original PCB outline
    [Controller-sketch.dxf, LR-sketch.dxf]
2017-03-18 Add some dimension annotations to user notes layer
    [Clicky SNES Controller Kicad.kicad_pcb]
2017-03-18 Add scanned notes about original circuit board
2017-03-18 Add FreeCAD project files for the DXF PCB outlines
    I'm not sure this is the best way to control FreeCAD documents.
    These particular files probably won't change much over time, though.
    [Controller-sketch.FCStd, LR-sketch.FCStd]
2017-03-19 Add SOIC-16 package footprint to the shift registers
    [Clicky SNES Controller Kicad.sch]
2017-03-19 Update footprint associations for the switches
    Added custom footprints for all the switches.
    [Clicky SNES Controller Kicad.sch]
2017-03-19 Set up OSH Park design rules
    [Clicky SNES Controller Kicad.kicad_pcb]
2017-03-19 Restart PCB with OSH Park blank template
    [Clicky SNES Controller Kicad.kicad_pcb]
2017-03-19 PCB Rev 2: Create basic board outline
    Re-imported the vector drawing of the mechanical board outline and put
    the mirrored copy on a different layer so it can be differentiated by
    color.
    Eco1.User is the unmirrored drawing.
    Eco2.User is the mirrored drawing
    Added some mechanical keep-out areas to these layers as well.
    I probably need two new layers for these but, for now, they are on the
    same user layers.
    The wide circles on Eco1.User are the keep-out areas behind the d-pad;
    so these will actually collide with components placed on the back side
    of the board.
    The wide circles on Eco2.User are the keep-out areas behind the ABXY
    buttons; so these will actually collide with components placed on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
    [Clicky SNES Controller Kicad.kicad_pcb]
2017-03-19 PCB Rev 2: Add mounting holes
    Added some drill holes to the main board.
    Still need to figure out the final position for the hole on the start /
    select board, but a placeholder is in the file for now.
    [Clicky SNES Controller Kicad.kicad_pcb]
2017-03-19 netlist: Update footprint associations
2017-03-20 SCH/NET: Attempt to fix issue with VDD/VSS labels on headers
    CN1 pin 1 was routed incorrectly and not labeled as VDD.
    Some of the other connectors don't have proper association with local
    VDD/VSS, nor do U1 and U2.
    This change mostly fixes it, but U1 is still showing raw VDD/VSS
    instead of the board-local VDD/VSS.
    [Clicky SNES Controller Kicad.sch]
2017-03-20 PCB: Import netlist and arrange large components
    This is a first pass at laying out the components.
    There is definitely a problem with the netlist, though.
    Many of the connectors are showing that they only have 1 pin instead of
    2 or 3.
    [Clicky SNES Controller Kicad.kicad_pcb]
2017-03-20 PCB: Update start/select button footprint
    Fixed a problem in the library with the soldermask covering these pads.
    [Clicky SNES Controller Kicad.kicad_pcb]
2017-03-25 Fix KiCad Project library paths
    I moved the custom library path to a subdirectory called "library"
    when I added the custom footprint and 3D models to that project.
2017-03-25 Schematic Rev 3 - Rework board-to-board jumpers
    Decided to go with 3 full size boards to fill the mechanical space in
    the controller instead of using the 3rd board as a spare.
    This allows to move CN1 and both ICs onto the center board, which now
    has plenty of space.
    This solves several problems working around plastic ridges behind the
    boards where I wanted to place components and reduces the number of
    board-to-board jumpers needed.
    [Clicky SNES Controller Kicad.sch]
2017-03-26 Change footprint for trigger connectors
    Change these to use .1" headers in case I want to add connectors
    later so that I can swap the trigger boards.
    [Clicky SNES Controller Kicad.sch]
2017-03-26 PCB: Update start/select button footprint
    [Clicky SNES Controller Kicad.kicad_pcb]
2017-03-26 PCB Rev 3: Import updated netlist
    Many components removed/updated so complex netlist import.
    Had to lock some manually placed pads (mounting holes).
    Added some additional keep-out regions for the main board:
    - There is cross on the top side of the main board
    - There is a ring behind the select/start buttons on the main board
    - I put these keep-outs on the Cmts.User layer
    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
    [Clicky SNES Controller Kicad.kicad_pcb]
2017-03-26 SCH/NET: Remove extra pullup, Rename CN1 PCB: Imported new netlist, Arranged resistors in order
    [Clicky SNES Controller Kicad.kicad_pcb, Clicky SNES Controller Kicad.sch]
2017-03-26 PCB: Place passive components
    [Clicky SNES Controller Kicad.kicad_pcb]
2017-03-26 Add title and revision to workshet notes
    [Clicky SNES Controller Kicad.kicad_pcb, Clicky SNES Controller Kicad.sch]
2017-03-26 PCB: Update custom trace widths
    Custmo values (sizes in mm):
    0.1524 - minimum trace size
    0.35 - SOIC-16 leg width
    0.58 - SOIC-16 pad width
    0.635 - .1" header pin width
    0.65 - gull-wing switch leg width
    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
    [Clicky SNES Controller Kicad.kicad_pcb]
2017-03-26 PCB: Route back side of board
    This is the simpler side of the board, but getting a basic layout
    in place will help when routing the top side as I will know where
    I can drop a via through to jump over other tracks.
    [Clicky SNES Controller Kicad.kicad_pcb]
2017-03-26 PCB: Minor optimization for back-side
    Noticed a missing GND route.
    Moved the DLATCH pullup resistor in order to facilitate some better
    pathing for the A_switch and GND nets.
    [Clicky SNES Controller Kicad.kicad_pcb]
2017-03-26 PCB: Add power tracks to top layer
    [Clicky SNES Controller Kicad.kicad_pcb]
2017-03-26 PCB: Move C2 to reduce GND loop area with U2
    [Clicky SNES Controller Kicad.kicad_pcb]
2017-03-26 PCB: Finish routing passives
    Had to fuss with the +5V route and placement of some of the
    resistors to get this to work out reasonably well.
    [Clicky SNES Controller Kicad.kicad_pcb]
2017-03-26 PCB: Route remaining Clock, Latch, and Serout nets
    [Clicky SNES Controller Kicad.kicad_pcb]
2017-03-26 PCB: Route ABXY_IN pins
    [Clicky SNES Controller Kicad.kicad_pcb]
2017-03-27 PCB: Route TR/TL jumper pins
    [Clicky SNES Controller Kicad.kicad_pcb]
2017-03-27 PCB: Route DPAD_IN pins
    [Clicky SNES Controller Kicad.kicad_pcb]
2017-03-27 PCB: Move TR/TL Connectors to avoid fouling on CN1
    These connectors were also swapped to the wrong side of the board
    which is partly why I didn't notice the mechanical collision.
    I'm debating whether they need to actually be moved to the DPAD
    and ABXY boards, but that is a pretty big tear up.
    Anyway, I took the opportunity to optimize some of the GND routing.
    [Clicky SNES Controller Kicad.kicad_pcb]
2017-03-27 Change color of F.Fab and B.Fab layer
    I guess this might just be a noop if the layer colors are stored in
    the general/global user preferences instead of in the project.
    [Clicky SNES Controller Kicad.kicad_pcb]
2017-03-27 PCB: Fix some DRC errors
    [Clicky SNES Controller Kicad.kicad_pcb]
2017-04-03 Documentation cleanup
    Used git filter-branch to remove copywrited documentation in preparation
    for uploading to github.
    Added a README to explain this and point to alternate sources of the
    documentation files.
    [ckswitches-KSC201GLFS.stp, ckswitches-KSC621GLFS.stp, ckswitches-KSC701GLFS.stp]
